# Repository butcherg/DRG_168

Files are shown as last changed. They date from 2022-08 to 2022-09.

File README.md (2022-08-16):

# DRG 168

Commputer-Aided-Design (CAD) files to produce a HOn3 model of Denver Rio Grande locomotive #168.  This steam locomotive operated on the DRG from about 1883 to 1933.  It was donated to the city of Colorado Springs, Colorado, where it was put on display in the downtown Antlers Park.  In 2015, it was leased to the Cumbres and Toltec Scenic Railroad (C&TS) for restoration to operation.  It now runs special trains on the C&TS from Antonito, Colorado.

The locomotive design was created using OpenSCAD, a script-based CAD, open-source.  This program may be downloaded at https://openscad.org/ 

The initial commit of files is a set of six .STL files that model the main engine parts, prepared specifically for stereolithography (SLA) 3D printing.  The file dimensions are expressed in millimeters, sized to produce HO scale (1/87) sized parts, for a 3 scale-foot gauged railway per the prototype gauge.

All artifacts in this repository are copyrighted 2022 by Glenn Butcher, all rights reserved.  The artifacts are licensed for use under the terms and conditions of the Creative Commons Attribution 4.0 International (CC BY 4.0) license, terms are available here: https://creativecommons.org/licenses/by/4.0/

Additionally, all artifacts in this repository are available "as-is", with no warranty of performance.

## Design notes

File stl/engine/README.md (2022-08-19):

# DRG #168 Engine Core

The six files in this directory are the core parts to assemble the basic
engine.  Their dimensions are expressed in millimeters to accommodate 3d printing. 
The have been designed to allow a number of fabrication alternatives, particularly 
printing the frame in metal or hand-fabication in brass.  

## Viewing

Included in this directory is the file 'integration.scad'.  It imports all 
the parts and renders them in their intended relationship to each other.  
You can view this file by downloading and installing OpenSCAD and simply 
opening the file.  Here's a render from the script:

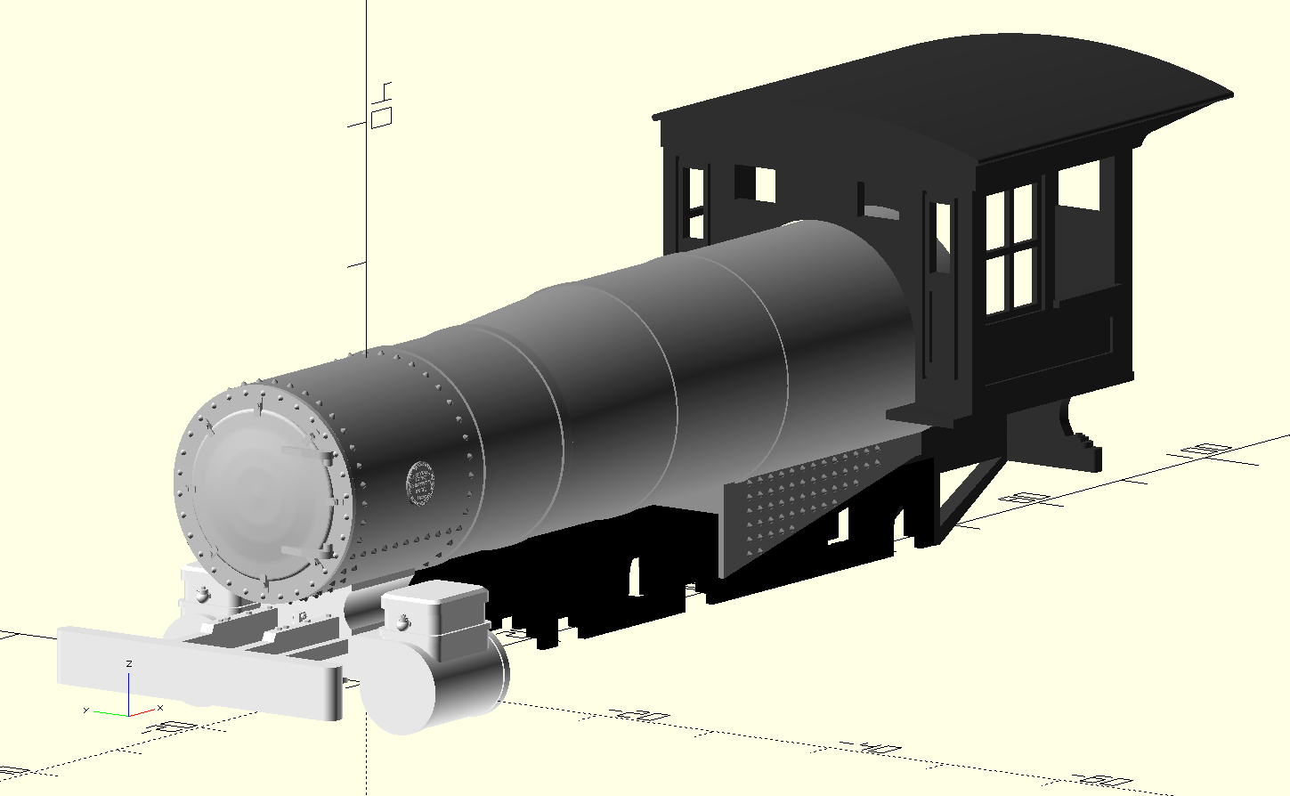
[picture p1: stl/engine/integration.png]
integration


## Printing

The detail embedded in the parts requires SLA (resin) printing to resolve. 
At 4k LCD resolution and 0.05mm layer height, the build plate is not
readable; let me know if a higher resolution will resove that.  For resin
printing, the cab, front end, smokebox front, and firebox backhead should be
printed at a 45-degree angle to minimize layer lines on surfaces.  The
firebox-boiler-smokebox assembly best prints vertical, to my limited
testing, but I'd be happy to hear of better alternatives.  

## Assembly

The engine parts require two 0-80 screws and nuts for assembly, one through
the cylinder chest into the smokebox (this screw will also attach the pilot
truck), and one through the rear frame through the cab attachment tab into
the firebox backhead base.  The smokebox and firebox backhead have nut
insets where the nuts can be glued with a small bit of CA adhesive.

The frame is designed to accommodate 12mm drivers on 1/8" axles from
Scalelink, https://www.scalelink.co.uk/.  They are to be held in place by a
0.02" thick brass plate, slightly smaller than 1/4" wide to fit in the
insets.  There are two 0-80 tappable screw holes in the frame bottom to
attach the plate.

## Modeling

These parts have been designed to accomodate variations in modeling; they
should support modeling of any of the T-12 class locomotives.  One exception
is the front end bolster; it is about 7 inches further forward than the
standard T-12, owing to the extension of the frame by the DRG to accommodate
a snowplow.  

Of note is that, for a powered model, the frame should be fabricated from
metal or a similarly stiff material.  The frame .stl should be
fabricate-able in Shapeways cast brass, but I haven't tried it yet.  You can
still print the frame in resin, but it won't be stiff enough to even tram
horizontally.  At this point, I believe the frame, crosshead guides, and
piston/main/siderods need to be made of metal...

The initial commit is way short of a fully-modeled locomotive.  I'm modeling
other parts/pieces for a complete locomotive that will eventually show up in
other directories of this repository.  Of note is that the backhead in the
initial commit is woefully bereft of detail; more is forthcoming.  For this
reason, you may want to avoid gluing the backhead to the cab...

These .stl files represent modeling accomplished in OpenSCAD scripts. 
Eventually, I'll also post these here, but that might take some time as they
need major re-organization to be proper engineering artifacts.

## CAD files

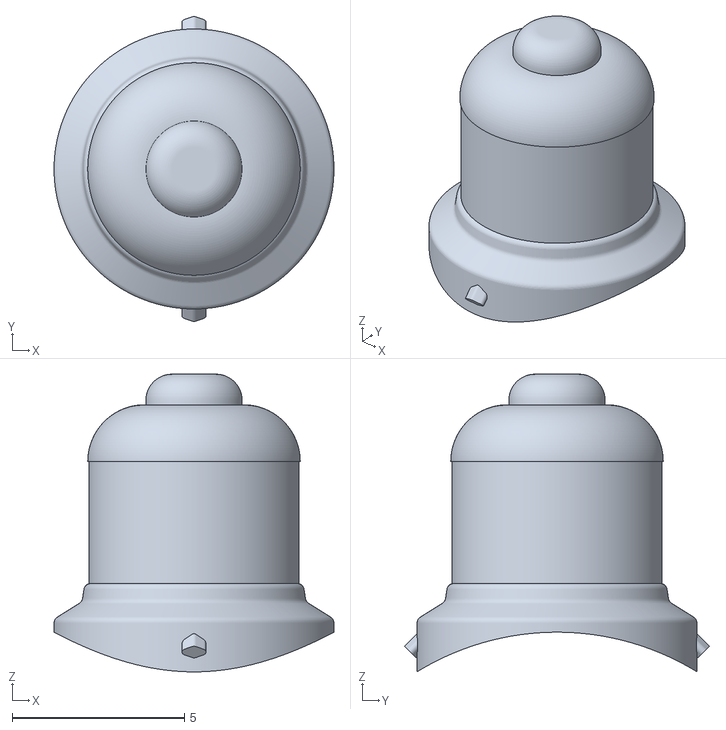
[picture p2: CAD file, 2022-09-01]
stl/decorations/sanddome_forprint.stl
8.13 x 8.86 x 8.64

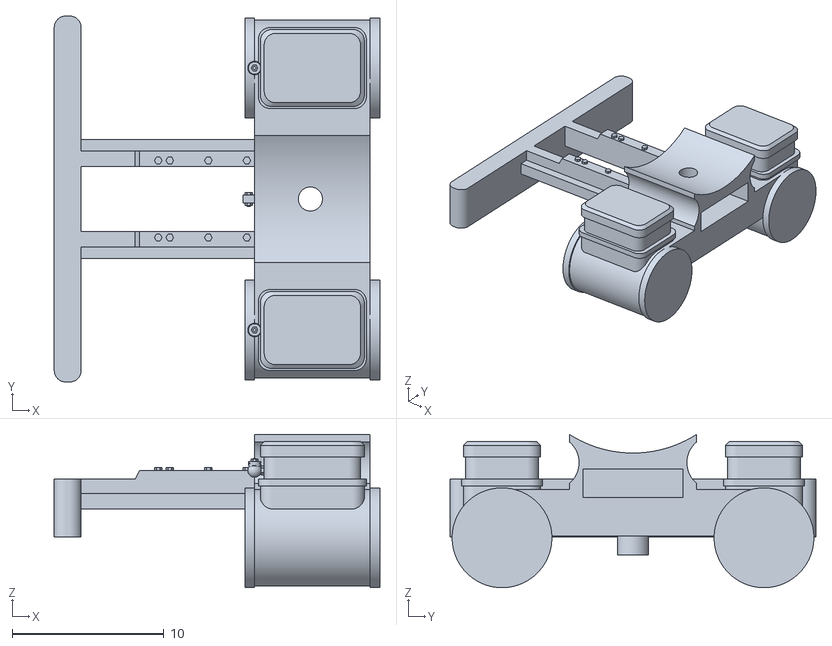
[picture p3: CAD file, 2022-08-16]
stl/engine/frontend_forprint.stl
21.5 x 24.1 x 10.1

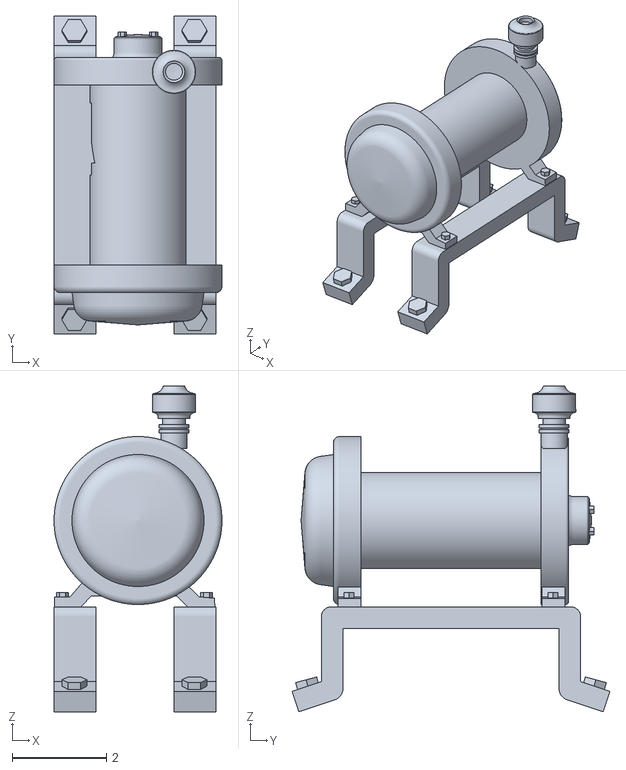
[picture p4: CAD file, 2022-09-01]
stl/decorations/generator_forprint.stl
3.56 x 6.73 x 6.90

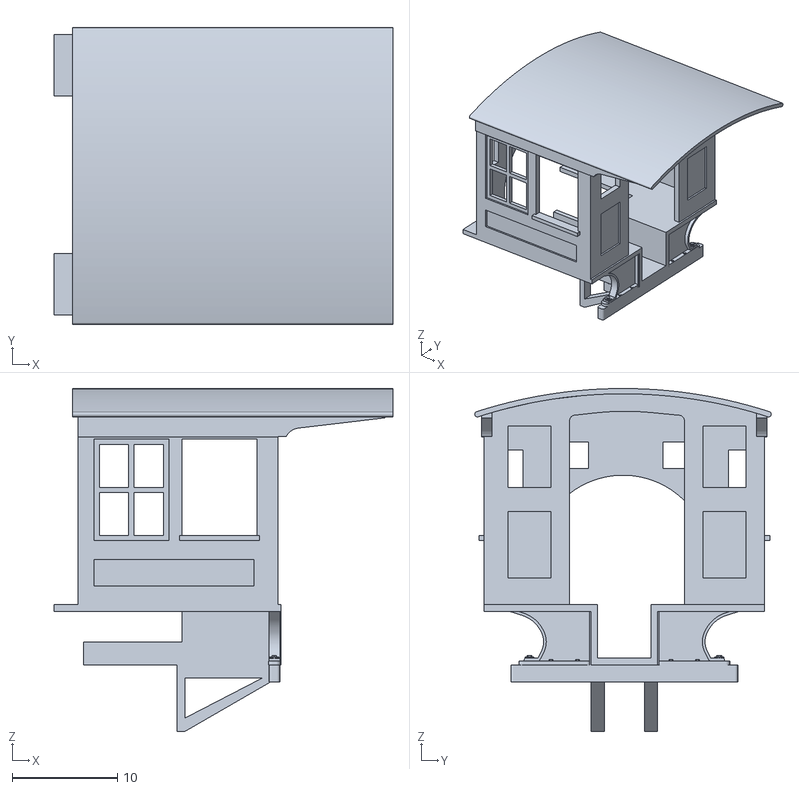
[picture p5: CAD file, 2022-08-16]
stl/engine/cab_forprint.stl
32.3 x 28.2 x 32.6

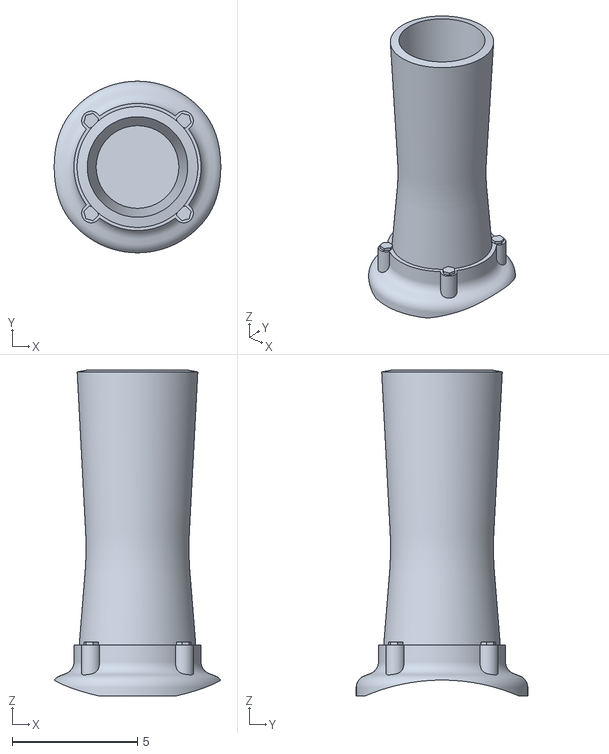
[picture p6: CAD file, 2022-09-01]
stl/decorations/smokestack_forprint.stl
6.66 x 6.86 x 13.0

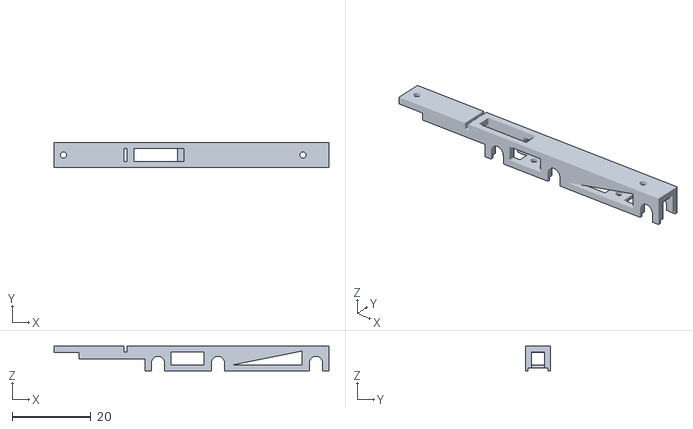
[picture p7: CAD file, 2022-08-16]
stl/engine/frame_forprint.stl
69.8 x 6.35 x 6.35

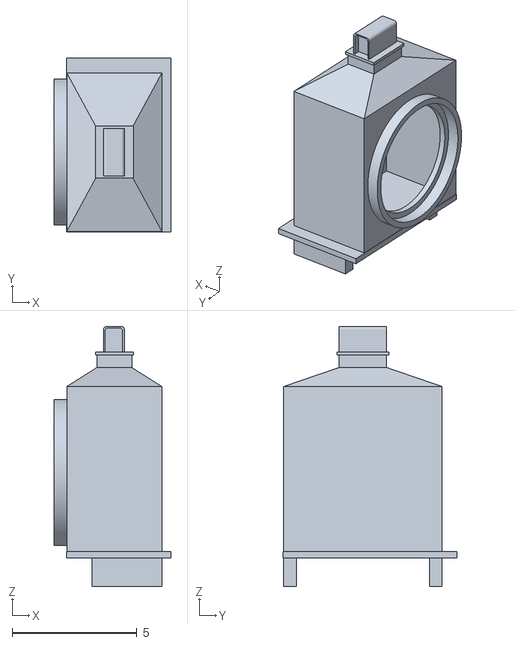
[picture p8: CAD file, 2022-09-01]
stl/decorations/headlamp_forprint.stl
4.68 x 6.98 x 10.4

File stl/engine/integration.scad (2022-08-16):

// A 'sanity-check' integration of the six main component .stl 
// files of the engine.
//
// Rotate around the model by holding down the left mouse button
// and dragging.  Slide the view around by doing the same thing, 
// but with the right mouse button.  Zoom in and out of the view
// with the mouse wheel.
//
// If you want to view only certain parts, put '//' in front of 
// the lines of parts you don't want to see, the press F5 to re-
// render the view.


color("#000000") import("frame_forprint.stl");
translate([53.6,0,6.3])  color("#333333") import("cab_forprint.stl");
translate([57.9,0,15.5]) color("#666666") import("firebox_backhead_forprint.stl");
translate([-12,0,7.65])  color("#999999") import("smokebox_boiler_firebox_forprint.stl");
translate([-12,0,15.38]) color("#CCCCCC") import("smokebox_front_forprint.stl");
translate([-19.06,0,2])  color("#FFFFFF") import("frontend_forprint.stl");

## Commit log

2022-08-16 moved engine .stl files to stl/engine
    [cab_forprint.stl, frame_forprint.stl, frontend_forprint.stl]
2022-08-16 added integration.scad
    [integration.scad]
2022-08-19 Update README.md
    added specification of measurement dimensions, millimeters.
2022-09-01 initial decorations
    [generator_forprint.stl, headlamp_forprint.stl, sanddome_forprint.stl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]
